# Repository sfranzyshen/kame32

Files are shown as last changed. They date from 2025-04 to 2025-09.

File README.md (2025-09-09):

# Kame32

<p align="center">
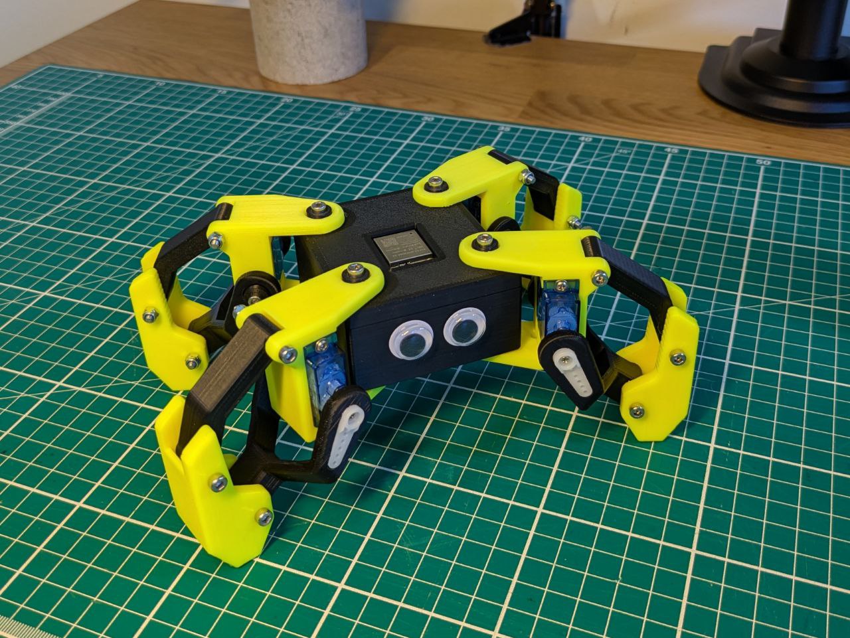
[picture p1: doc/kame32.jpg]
  
</p>

# License 
This robot is licensed under a [Creative Commons Attribution-ShareAlike 4.0 International License](http://creativecommons.org/licenses/by-sa/4.0/).

<p align="center">
  
</p>

## this is a sfranzyshen fork ... refer to original

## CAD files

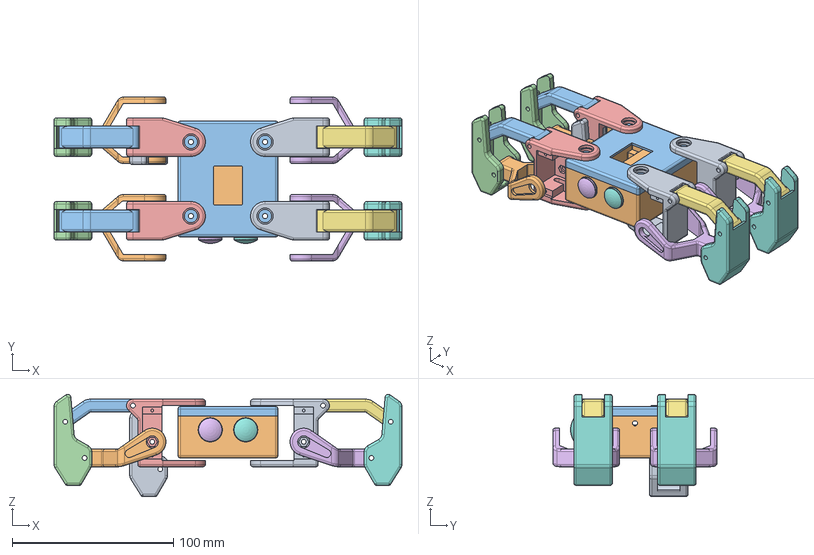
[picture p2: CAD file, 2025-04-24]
3d/freecad/kame32.FCStd
216.0 x 102.0 x 63.5 mm
foot
legB001
legA001
foot001
bracket001
legB001 (Mirror #1)
legA001 (Mirror #2)
foot001 (Mirror #3)
bracket001 (Mirror #4)
legB001 (Mirror #5)
legA001 (Mirror #6)
foot001 (Mirror #7)
bracket001 (Mirror #8)
legB001 (Mirror #9)
legA001 (Mirror #10)
foot001 (Mirror #11)
bracket001 (Mirror #12)
Cuerpo
Cuerpo001
eye-base
black-eye
eye-cover
eye-base001
eye-cover001
black-eye001
Cuerpo002

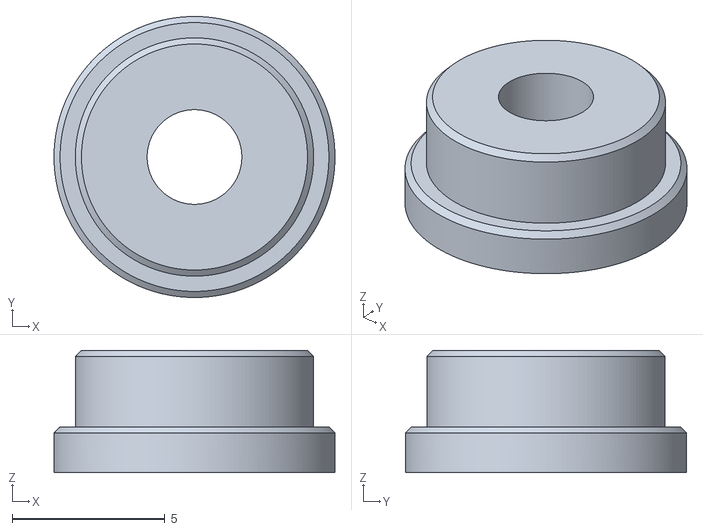
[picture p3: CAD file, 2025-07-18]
3d/stl/bushing.stl
9.20 x 9.20 x 4.00

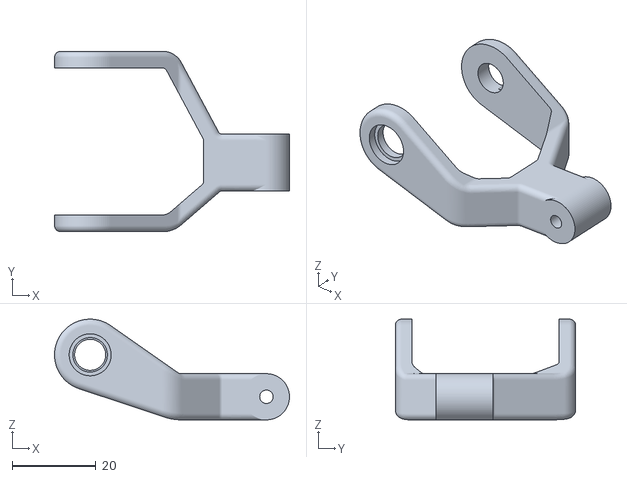
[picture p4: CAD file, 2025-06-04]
3d/stl/leg-right-mg90s.stl
56.0 x 43.0 x 24.0

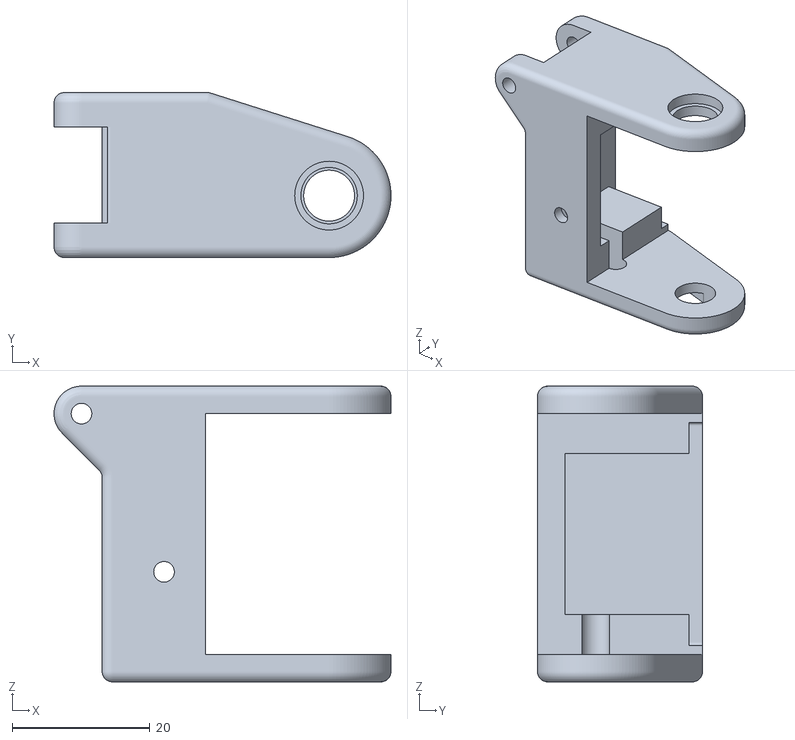
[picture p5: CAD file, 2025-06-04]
3d/stl/bracket-left-mg90s.stl
49.0 x 24.0 x 43.0

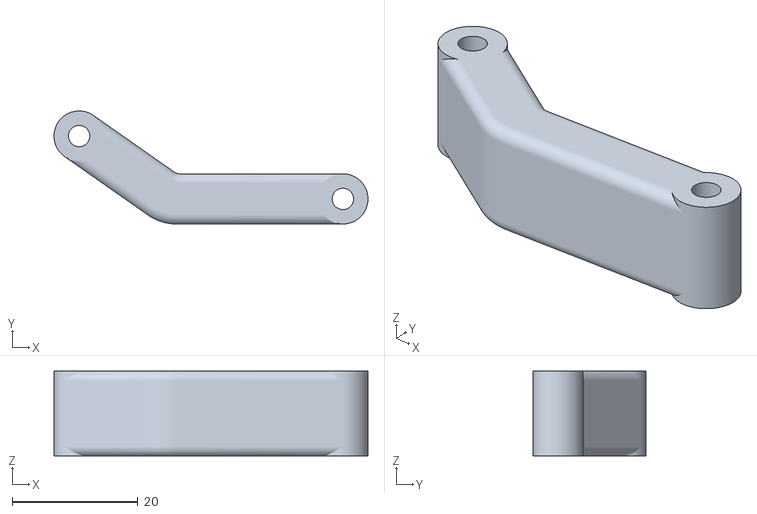
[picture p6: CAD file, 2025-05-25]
3d/stl/leg-link.stl
50.0 x 18.0 x 13.5

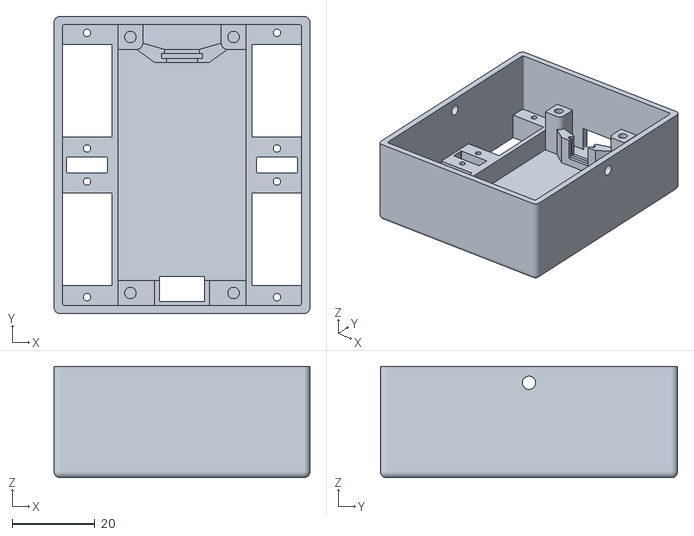
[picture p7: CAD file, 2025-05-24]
3d/stl/body-box.stl
62.0 x 72.0 x 27.0

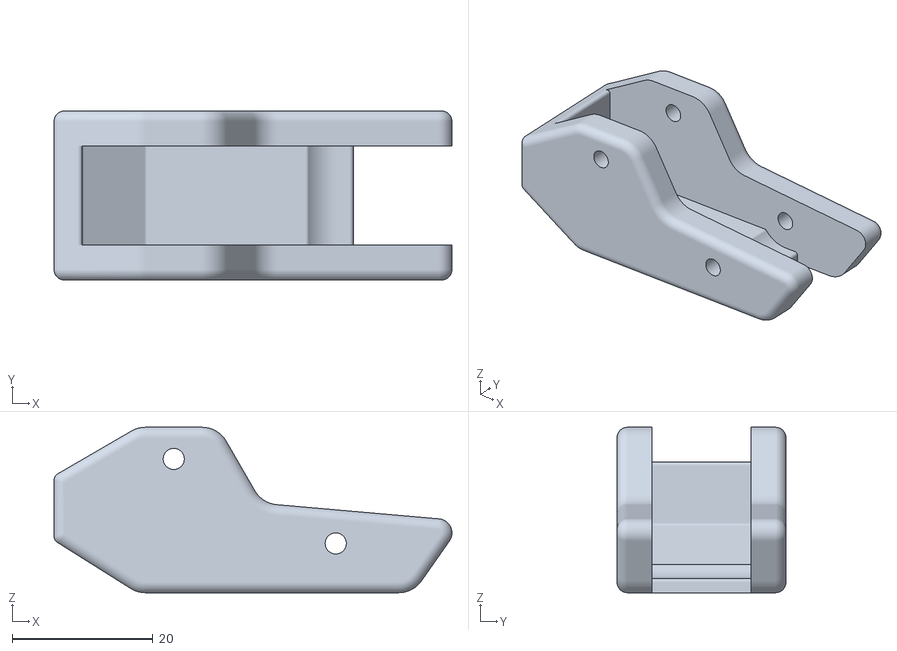
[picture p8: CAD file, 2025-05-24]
3d/stl/foot.stl
56.5 x 24.0 x 23.5

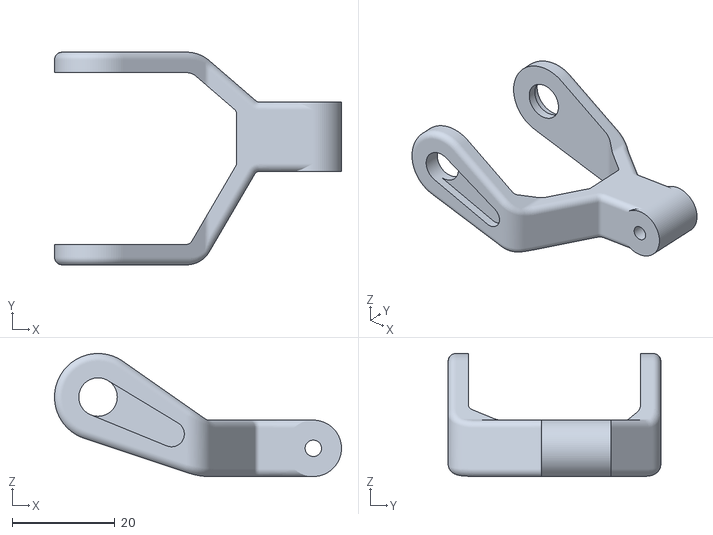
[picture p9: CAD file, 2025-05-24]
3d/stl/leg-left-sg90.stl
56.0 x 41.5 x 24.0

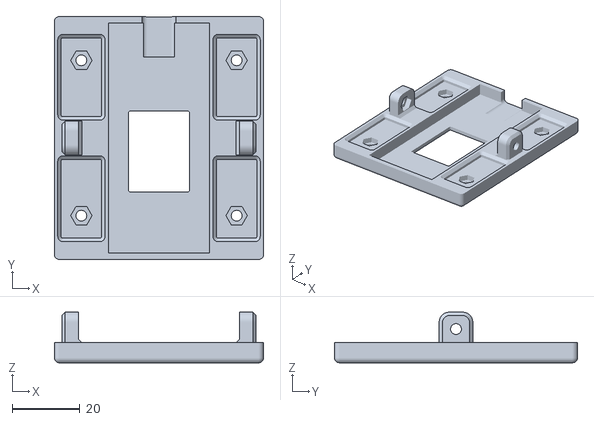
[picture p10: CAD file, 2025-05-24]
3d/stl/body-cover.stl
62.0 x 72.0 x 15.0

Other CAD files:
3d/stl/leg-left-mg90s.stl
3d/stl/bracket-right-mg90s.stl
3d/stl/bracket-right-sg90.stl
3d/stl/bracket-left-sg90.stl
3d/stl/leg-right-sg90.stl

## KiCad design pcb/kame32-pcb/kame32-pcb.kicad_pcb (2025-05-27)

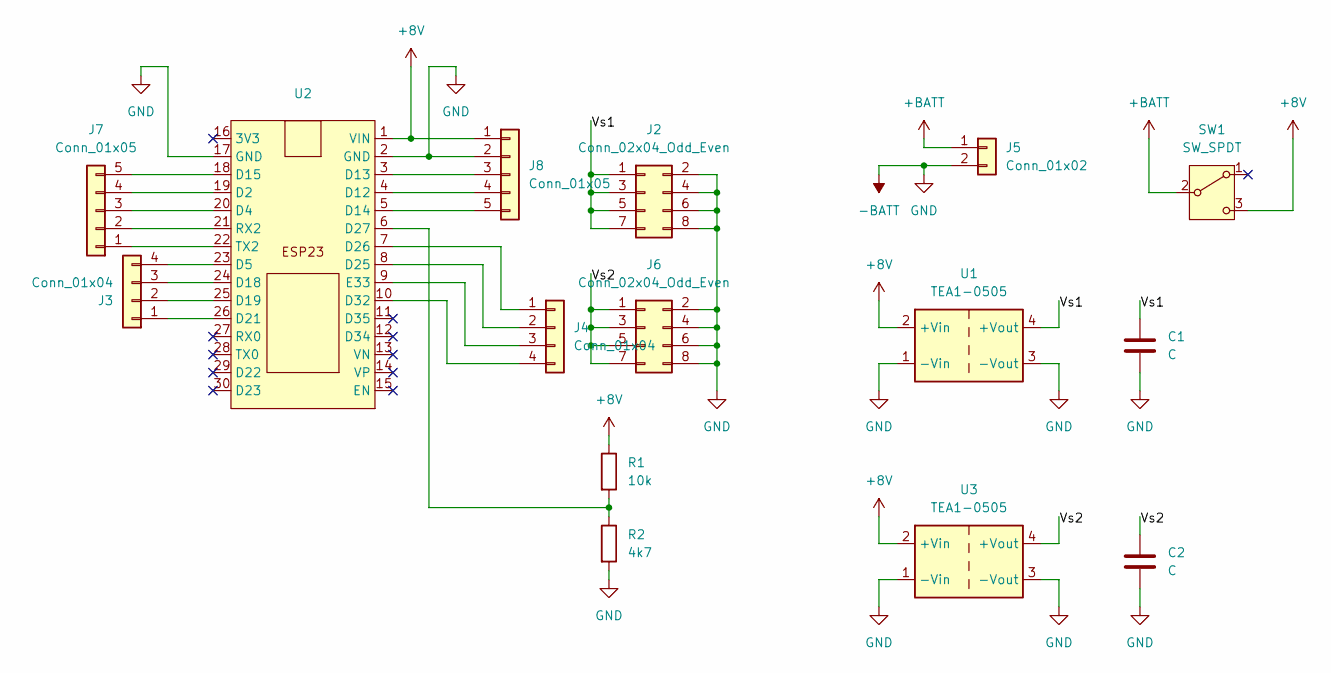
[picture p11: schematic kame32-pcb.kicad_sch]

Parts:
C1, C2: C; CP_Radial_D5.0mm_P2.50mm
J2, J6: Conn_02x04_Odd_Even; PinHeader_2x04_P2.54mm_Vertical
J3, J4: Conn_01x04; PinHeader_1x04_P2.54mm_Vertical
J5: Conn_01x02; PinHeader_1x02_P2.54mm_Vertical
J7, J8: Conn_01x05; PinHeader_1x05_P2.54mm_Vertical
R1: 10k; R_Axial_DIN0204_L3.6mm_D1.6mm_P7.62mm_Horizontal
R2: 4k7; R_Axial_DIN0204_L3.6mm_D1.6mm_P7.62mm_Horizontal
SW1: SW_SPDT; SW_XKB_DM1-16UP-1
U1, U3: TEA1-0505; dcdc
U2: PinHeader_1x30_P2.54mm_Vertical

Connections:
+8V: J8.1, R1.1, SW1.3 (C), U1.2 (+Vin), U2.1 (VIN), U3.2 (+Vin)
+BATT: J5.1, SW1.2 (B)
-BATT: C1.2, C2.2, J2.2, J2.4, J2.6, J2.8, J5.2, J6.2, J6.4, J6.6, J6.8, J8.2, R2.2, U1.1 (-Vin), U1.3 (-Vout), U2.2 (GND), U2.17 (GND), U3.1 (-Vin), U3.3 (-Vout)
/Vs1: C1.1, J2.1, J2.3, J2.5, J2.7, U1.4 (+Vout)
/Vs2: C2.1, J6.1, J6.3, J6.5, J6.7, U3.4 (+Vout)
unnamed: J3.1, U2.26 (D21)
unnamed: J3.2, U2.25 (D19)
unnamed: J3.3, U2.24 (D18)
unnamed: J3.4, U2.23 (D5)
unnamed: J4.1, U2.7 (D26)
unnamed: J4.2, U2.8 (D25)
unnamed: J4.3, U2.9 (E33)
unnamed: J4.4, U2.10 (D32)
unnamed: J7.1, U2.22 (TX2)
unnamed: J7.2, U2.21 (RX2)
unnamed: J7.3, U2.20 (D4)
unnamed: J7.4, U2.19 (D2)
unnamed: J7.5, U2.18 (D15)
unnamed: J8.3, U2.3 (D13)
unnamed: J8.4, U2.4 (D12)
unnamed: J8.5, U2.5 (D14)
unnamed: R1.2, R2.1, U2.6 (D27)

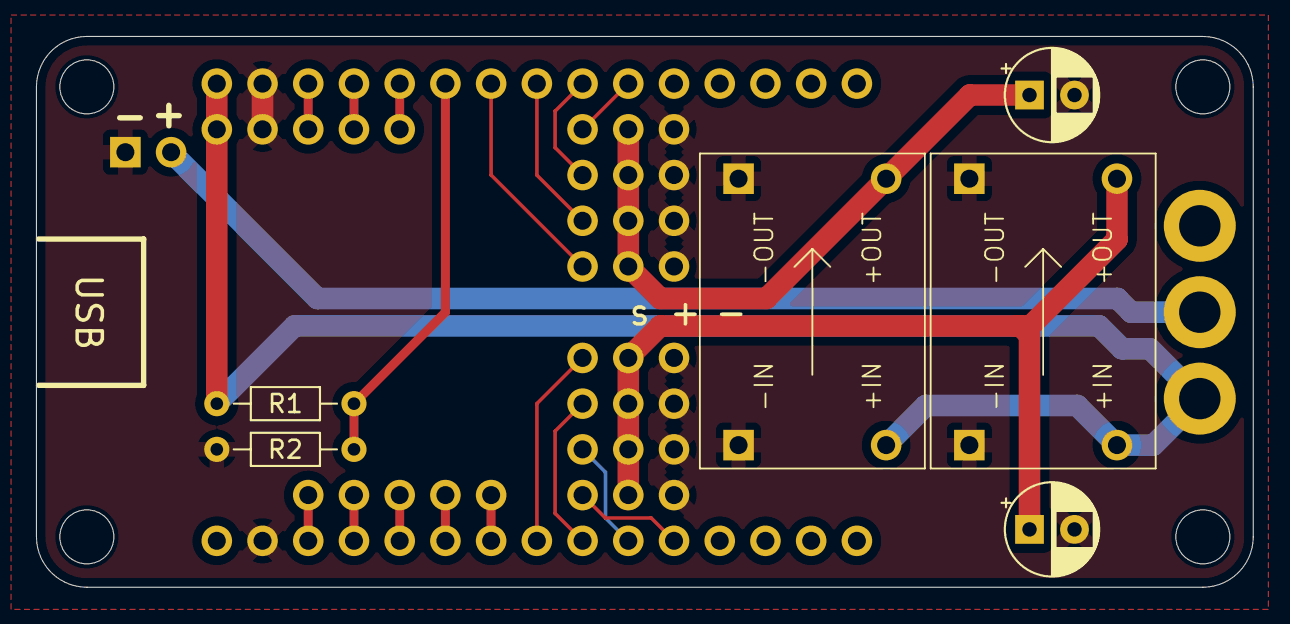
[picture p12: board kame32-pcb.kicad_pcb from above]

Board: 2 copper layers, 67.6 x 30.6 mm, 15 parts (1 on the bottom side), 22 nets.

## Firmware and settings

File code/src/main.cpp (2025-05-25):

//  Servos:
//
//  |\ ____   ________   ______/|
//  |(2)___)(0)      (1)(____(3)|
//  |__/    |   KAME   |     \__|
//          |          |
//  |\_____ |          | ______/|
//  |(6)___)(4)______(5)(____(7)|
//  |__/                     \__|
//               / \
//                |
//           USBs |

#include <ESP32Servo.h>
#include <WiFi.h>
#include <WebServer.h>
#include <ESPmDNS.h>
#include <web_template.h>
#include <minikame.h>

#define SSID        "Kame32"
#define PASSWORD    "00000000"
#define LED_PIN     2

MiniKame robot;
WebServer server(80);
String command = "";

int getBatteryPercent() {
    int raw = analogRead(34);
    int percent = map(raw, 0, 4095, 0, 100);
    return percent;
}

String getBatteryIcon(int percent) {
    if (percent > 80)
        return "[█████]";
    else if (percent > 60)
        return "[████ ]";
    else if (percent > 40)
        return "[███  ]";
    else if (percent > 20)
        return "[██   ]";
    else
        return "[█    ]";
}

String generateHTML(String ip, int batteryPercent) {
    String html = htmlTemplate;
    html.replace("{{IP}}", ip);
    html.replace("{{BATT_PERCENT}}", String(batteryPercent));
    html.replace("{{BATT_ICON}}", getBatteryIcon(batteryPercent));
    return html;
}

void handleRoot() {
    int battery = getBatteryPercent();
    String ip = WiFi.softAPIP().toString();
    server.send(200, "text/html", generateHTML(ip, battery));
}

void handleCmd() {
    if (server.hasArg("val")) {
        command = server.arg("val");
        Serial.println("New command: " + command);
    }
    server.send(200, "text/plain", "OK");
}

void spinner(uint32_t ms) {
    uint32_t start = millis();
    while (millis() - start < ms) {
        server.handleClient();
    }
}

void setup() {
    Serial.begin(115200);
    robot.init();
    robot.home();

    pinMode(LED_PIN, OUTPUT);
    digitalWrite(LED_PIN, LOW);

    WiFi.mode(WIFI_AP);
    WiFi.softAP(SSID, PASSWORD);
    Serial.println(WiFi.softAPIP());
    MDNS.begin("kame32");

    server.on("/", handleRoot);
    server.on("/cmd", handleCmd);
    server.begin();
}

void loop() {
    server.handleClient();
    if (command != "") {
        digitalWrite(LED_PIN, HIGH);
        if (command == "forward") {
            robot.walk(1, 500);
        } else if (command == "left") {
            robot.turnL(1, 500);
        } else if (command == "right") {
            robot.turnR(1, 500);
        } else if (command == "backward") {
            robot.backward(1, 500);
        } else if (command == "hello") {
            robot.hello();
        } else if (command == "jump") {
            robot.jump();
        } else if (command == "pushup") {
            robot.pushUp(2, 2000);
        } else if (command == "dance") {
            robot.dance(1, 500);
        } else if (command == "moonwalk") {
            robot.moonwalkL(1, 500);
        } else if (command == "frontback") {
            robot.frontBack(1, 500);
        } else {
            robot.home();
        }
        digitalWrite(LED_PIN, LOW);
    }
}

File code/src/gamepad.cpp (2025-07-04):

#include <WiFi.h>
#include <WebServer.h>
#include <ESPmDNS.h>
#include <config.h>
#include <kame.h>
#include <gamepad.h>


Kame robot;
WebServer server(80);

int joy_x = 0;
int joy_y = 0;

float progress = 0;
float period = 450;
float leg_spread = 20;
float body_height = 10;
float body_shift = 0;
float step_amplitude = 0;
float step_height = 20;

float phase_linear[] =  {90,  90,  270, 90,  270, 270, 90,  270};
float phase_angular[] = {90,  270, 270, 90,  270, 90,  90,  270};
float phase[] =         {0,   0,   0,   0,   0,   0,   0,   0};


void handleRoot() {
    server.send(200, "text/html", gamepad_html);
}

void handleJoystick() {
    if (server.hasArg("x") && server.hasArg("y")) {
        joy_x = server.arg("x").toInt();
        joy_y = server.arg("y").toInt();
        server.send(200, "text/plain", "OK");
    } else {
        server.send(400, "text/plain", "Missing x or y");
    }
}

void handleButton() {
    if (server.hasArg("label")) {
        String label = server.arg("label");
        Serial.println(label);
        if (label == "A") {
            robot.hello();
        } else if (label == "B") {
            robot.jump();
        } else if (label == "C") {
            robot.pushUp(4, 1000);
        } else if (label == "X") {
            robot.dance(2, 1000);
        } else if (label == "Y") {
            robot.moonwalkL(2, 2000);
        } else if (label == "Z") {
            robot.frontBack(2, 1000);
        } else if (label == "Start") {
            robot.arm();
        } else if (label == "Stop") {
            robot.disarm();
        } else {
            Serial.println("Unknown button: " + label);
        }
        server.send(200, "text/plain", "Button OK");
    } else {
        server.send(400, "text/plain", "Missing label");
    }
}


void setup() {
    Serial.begin(115200);

    WiFi.mode(WIFI_AP);
    WiFi.softAP(SSID, PASSWORD);
    // WiFi.mode(WIFI_STA);
    // WiFi.begin(SSID, PASSWORD);
    MDNS.begin(HOSTNAME);
    
    robot.init();
    robot.loadCalibration();
    robot.home();

    server.on("/", handleRoot);
    server.on("/joystick", handleJoystick);
    server.on("/button", handleButton);
    server.begin();
}

void loop() {
    server.handleClient();

    progress += robot.oscillator[0].getPhaseProgress();
    while (progress > 360)
        progress -= 360;

    if (abs(joy_x) > 0.0 || abs(joy_y) > 0.0) {
        if (abs(joy_y) >= abs(joy_x)) {
            // Linear movement
            step_amplitude = joy_y * 0.25;
            body_shift = step_amplitude * 0.8;

            phase[0] = phase_linear[0] + progress;
            phase[1] = phase_linear[1] + progress;
            phase[2] = phase_linear[2] + 2 * progress;
            phase[3] = phase_linear[3] + 2 * progress;
            phase[4] = phase_linear[4] + progress;
            phase[5] = phase_linear[5] + progress;
            phase[6] = phase_linear[6] + 2 * progress;
            phase[7] = phase_linear[7] + 2 * progress;
        } else {
            // Angular movement
            step_amplitude = joy_x * 0.25;
            body_shift = 0.0;

            phase[0] = phase_angular[0] + progress;
            phase[1] = phase_angular[1] + progress;
            phase[2] = phase_angular[2] + 2 * progress;
            phase[3] = phase_angular[3] + 2 * progress;
            phase[4] = phase_angular[4] + progress;
            phase[5] = phase_angular[5] + progress;
            phase[6] = phase_angular[6] + 2 * progress;
            phase[7] = phase_angular[7] + 2 * progress;
        }

        for (int i = 0; i < 8; i++) {
            robot.oscillator[i].setPhase(phase[i]);
            robot.oscillator[i].reset();
        }

        robot.oscillator[0].setAmplitude(step_amplitude);
        robot.oscillator[1].setAmplitude(step_amplitude);
        robot.oscillator[4].setAmplitude(step_amplitude);
        robot.oscillator[5].setAmplitude(step_amplitude);

        robot.oscillator[2].setAmplitude(step_height);
        robot.oscillator[3].setAmplitude(step_height);
        robot.oscillator[6].setAmplitude(step_height);
        robot.oscillator[7].setAmplitude(step_height);

        robot.oscillator[0].setOffset(90 + leg_spread - body_shift);
        robot.oscillator[1].setOffset(90 - leg_spread + body_shift);
        robot.oscillator[4].setOffset(90 - leg_spread - body_shift);
        robot.oscillator[5].setOffset(90 + leg_spread + body_shift);

        robot.oscillator[2].setOffset(90 - body_height);
        robot.oscillator[3].setOffset(90 + body_height);
        robot.oscillator[6].setOffset(90 + body_height);
        robot.oscillator[7].setOffset(90 - body_height);

        robot.oscillator[0].setPeriod(period);
        robot.oscillator[1].setPeriod(period);
        robot.oscillator[4].setPeriod(period);
        robot.oscillator[5].setPeriod(period);

        robot.oscillator[2].setPeriod(period / 2);
        robot.oscillator[3].setPeriod(period / 2);
        robot.oscillator[6].setPeriod(period / 2);
        robot.oscillator[7].setPeriod(period / 2);

        robot.setServo(0, robot.oscillator[0].refresh());
        robot.setServo(1, robot.oscillator[1].refresh());
        robot.setServo(4, robot.oscillator[4].refresh());
        robot.setServo(5, robot.oscillator[5].refresh());

        if (progress < 180) {
            robot.setServo(3, robot.oscillator[3].refresh());
            robot.setServo(6, robot.oscillator[6].refresh());
        } else {
            robot.setServo(2, robot.oscillator[2].refresh());
            robot.setServo(7, robot.oscillator[7].refresh());
        }
    }
    else{
        robot.home();
    }
}

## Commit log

2025-04-23 pcb files
    [kame32-pcb.kicad_pcb, kame32-pcb.kicad_sch]
2025-04-24 3d model
    [kame32.FCStd]
2025-04-29 fix body sockets in freecad model
2025-05-08 PCB before DCDC change
    [kame32-pcb.kicad_pcb, kame32-pcb.kicad_sch]
2025-05-24 tested 3d model
    [body-box.stl, body-cover.stl, bracket-left-mg90s.stl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]
2025-05-25 added leg-link missing part
    [leg-link.stl]
2025-05-25 add bushing
    [bushing.stl]
2025-05-27 esp32 pcb with servo headers
    [kame32-pcb-B_Cu.gbr, kame32-pcb-B_Mask.gbr, kame32-pcb-B_Silkscreen.gbr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]
2025-06-02 fix horn room for mg90s parts
    [bracket-left-mg90s.stl, bracket-right-mg90s.stl, leg-left-mg90s.stl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]
2025-06-04 working in calibration interface
2025-06-04 improved calibration ui (dark theme matching web)
2025-06-04 bigger tolerances for mg90s parts
    [bracket-left-mg90s.stl, bracket-right-mg90s.stl, leg-left-mg90s.stl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]
2025-06-07 interface to calibrate servos
2025-06-12 apply calibration values
2025-06-17 migrate servo control to native functions
2025-07-04 Gamepad with joystick and buttons
2025-07-18 updated bushing stl
    [bushing.stl]

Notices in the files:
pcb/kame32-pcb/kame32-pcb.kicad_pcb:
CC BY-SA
